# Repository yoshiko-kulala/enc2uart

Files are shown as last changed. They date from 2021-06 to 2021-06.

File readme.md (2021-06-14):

# enc2uart
とある理由でエンコーダを複数arduinoで読む必要出たので作った  
[nucleo-F401RE](https://akizukidenshi.com/catalog/g/gM-07723/)でエンコーダを4つ読んでuartで送っている  

## Hou to use  
### シールド基板、エンコーダとの配線
使用時にはこのようなシールド基板を用いて動作させている  
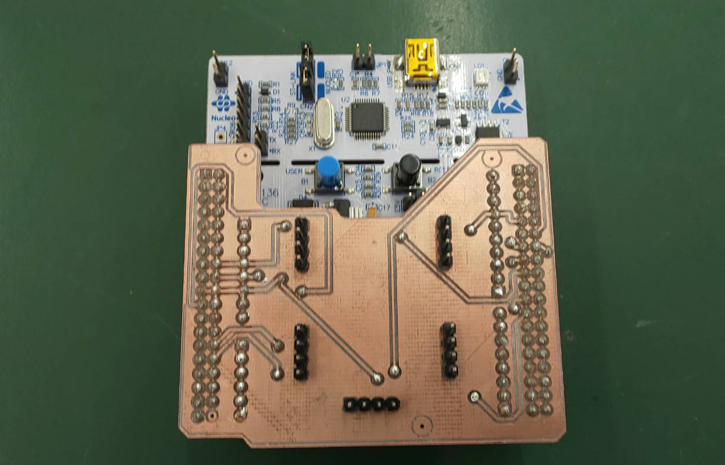
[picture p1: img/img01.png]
  
基板のkicadデータ、ガーバーは[circuit/encoder](https://github.com/yoshiko-kulala/enc2uart/tree/master/circuit/encoder)にある  
回路図は最新だが、ボード図はプルアップ抵抗のないものになっている  

実際にはこのように配線すればOK  
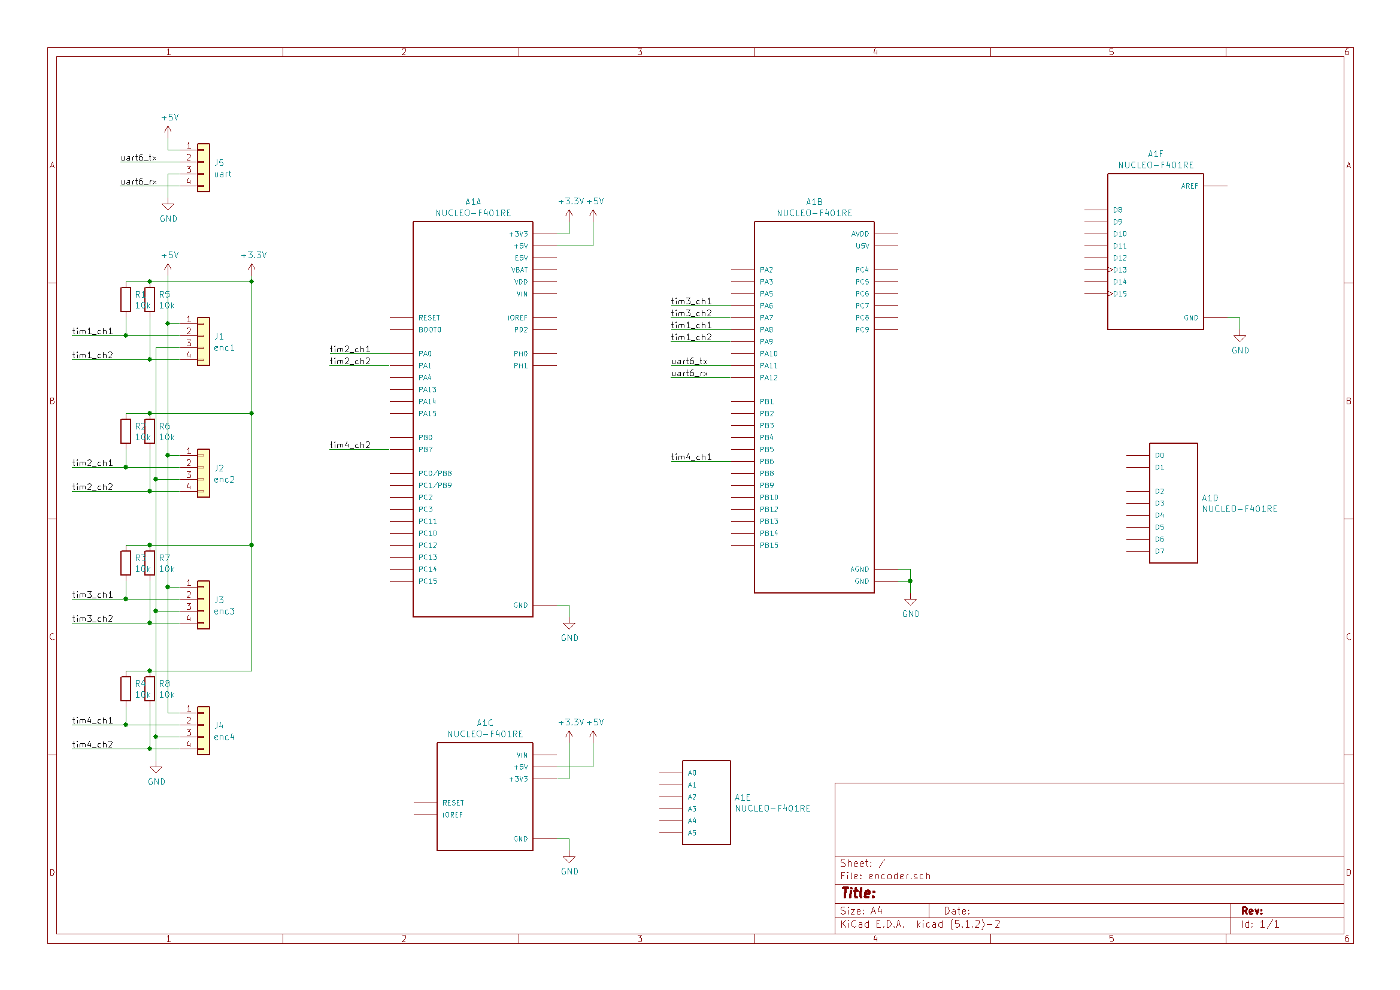
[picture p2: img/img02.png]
  

### arduinoとの接続  
[arduino nano every](https://akizukidenshi.com/catalog/g/gM-14848/)を用いたのでserial1を使っている  
arduinoによっては[SoftwareSerial](http://www.musashinodenpa.com/arduino/ref/index.php?f=1&pos=120)でも同様に動作可能と思う  
f401側のuartとarduino側のuartを接続すればOK  
今回は下図のように接続した
| [arduino nano every](https://akizukidenshi.com/catalog/g/gM-14848/) | [nucleo-F401RE](https://akizukidenshi.com/catalog/g/gM-07723/) |
| --- | --- |
| 5V | 5V(arduinoから給電する場合) |
| D0 | Tx |
| GND | GND |
| D1 | Rx |

## プログラムサンプル
nucleo側プログラムは[src/encoder_test](https://github.com/yoshiko-kulala/enc2uart/tree/master/src/encoder_test)にある  
CubeIDEでそのまま書き込める(と思う)  

arduino側のプログラムは[src/read_data](https://github.com/yoshiko-kulala/enc2uart/tree/master/src/read_data)にある  
これもarduinoIDEで特に問題なく書き込めると思う  

## メモ
- データの中身
実際に送ってる値は10msごとのパルスの増減  
特に計算してないのでエンコーダの分解能によってarduino側(もしくはnucleo)で処理されたし  
- 送信時の話し  
エンコーダ1つに10bit、4つで40bitなので5byteにして送信している  
つまるところ、100msに512パルス以上来るとオーバーする  
特にその辺の処理入れてないので将来的に追加するかも  
- nucleoからのデバッグ  
nucleoとpcをusb接続して、teratermとかで115200bpsとかで読んでもらうと各エンコーダの値が出力される  
これが0ならエンコーダとnucleo間が怪しい  
これが出てたらnucleoとarduino間が怪しい

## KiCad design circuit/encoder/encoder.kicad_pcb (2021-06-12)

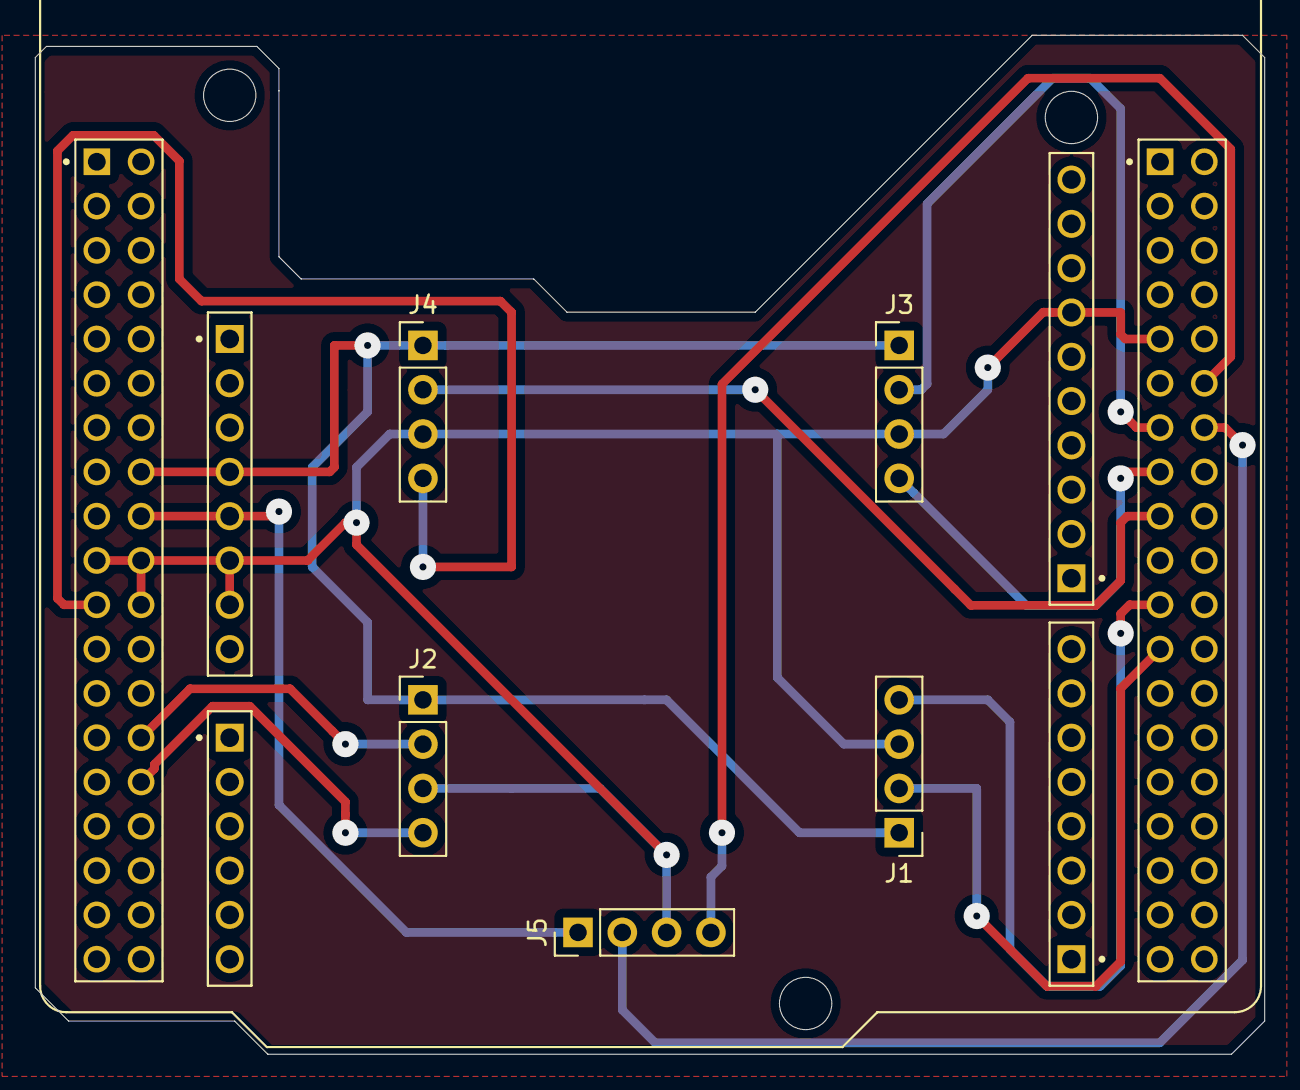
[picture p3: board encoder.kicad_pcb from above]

Board: 2 copper layers, 70.5 x 58.4 mm, 6 parts (0 on the bottom side), 13 nets.

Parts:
A1: NUCLEO-F401RE; ST_NUCLEO-F401RE
J1: enc1; PinHeader_1x04_P2.54mm_Vertical
J2: enc2; PinHeader_1x04_P2.54mm_Vertical
J3: enc3; PinHeader_1x04_P2.54mm_Vertical
J4: enc4; PinHeader_1x04_P2.54mm_Vertical
J5: uart; PinHeader_1x04_P2.54mm_Vertical

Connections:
+3V3: A1.CN6_4, A1.CN7_16, J1.1, J2.1, J3.1, J4.1
+5V: A1.CN6_5, A1.CN7_18, J5.1
/tim1_ch1: A1.CN10_23, J1.2
/tim1_ch2: A1.CN10_21, J1.4
/tim2_ch1: A1.CN7_28, J2.2
/tim2_ch2: A1.CN7_30, J2.4
/tim3_ch1: A1.CN10_13, J3.2
/tim3_ch2: A1.CN10_15, J3.4
/tim4_ch1: A1.CN10_17, J4.2
/tim4_ch2: A1.CN7_21, J4.4
/uart6_rx: A1.CN10_12, J5.4
/uart6_tx: A1.CN10_14, J5.2
GND: A1.CN5_7, A1.CN6_6, A1.CN6_7, A1.CN7_8, A1.CN7_19, A1.CN7_20, A1.CN7_22, A1.CN10_9, A1.CN10_20, A1.CN10_32, J1.3, J2.3, J3.3, J4.3, J5.3

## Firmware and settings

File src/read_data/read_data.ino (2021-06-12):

uint8_t buf[4];
int rpm[4];
int prerpm[4];

void setup() {
  Serial.begin(115200);
  while (!Serial) {
  }

  Serial1.begin(115200);
}

void loop() { // run over and over
  if (Serial1.available() >4) {
    for (int i = 0; i < 5; i++) {
      buf[i] = Serial1.read();
    }
    //    Serial.print(buf[0]);
    //    Serial.print(",");
    //    Serial.print(buf[1]);
    //    Serial.print(",");
    //    Serial.print(buf[2]);
    //    Serial.print(",");
    //    Serial.print(buf[3]);
    //    Serial.print(",");
    //    Serial.println(buf[4]);
    for(int i=0;i<4;i++)prerpm[i]=rpm[i];    
    rpm[0] = buf[0] + ((buf[1] & 0x3) << 8);
    rpm[1] = ((buf[1] & 0xFC)>>2) + ((buf[2] & 0xF) << 6);
    rpm[2] = ((buf[2] & 0xF0)>>4) + ((buf[3] & 0x3F) << 4);
    rpm[3] = ((buf[3] & 0xC0)>>8) + (buf[4] << 2);
    for(int i=0;i<4;i++){
      rpm[i]=rpm[i]-500;
      if(abs(prerpm[i]-rpm[i])>40)rpm[i]=prerpm[i];
    }
    Serial.print(rpm[0]);
    Serial.print(",");
    Serial.print(rpm[1]);
    Serial.print(",");
    Serial.print(rpm[2]);
    Serial.print(",");
    Serial.println(rpm[3]);
  }
}

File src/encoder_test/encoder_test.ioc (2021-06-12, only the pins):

Mcu.UserName=STM32F401RETx
PA0-WKUP.Signal=S_TIM2_CH1_ETR
PA1.Signal=S_TIM2_CH2
PA11.Signal=USART6_TX
PA12.Signal=USART6_RX
PA13.GPIO_Label=TMS
PA13.Signal=SYS_JTMS-SWDIO
PA14.GPIO_Label=TCK
PA14.Signal=SYS_JTCK-SWCLK
PA2.GPIO_Label=USART_TX
PA2.Signal=USART2_TX
PA3.GPIO_Label=USART_RX
PA3.Signal=USART2_RX
PA5.GPIO_Label=LD2 [Green Led]
PA5.Signal=GPIO_Output
PA6.Signal=S_TIM3_CH1
PA7.Signal=S_TIM3_CH2
PA8.Signal=S_TIM1_CH1
PA9.Signal=S_TIM1_CH2
PB3.GPIO_Label=SWO
PB3.Signal=SYS_JTDO-SWO
PB6.Signal=S_TIM4_CH1
PB7.Signal=S_TIM4_CH2
PC13-ANTI_TAMP.GPIO_Label=B1 [Blue PushButton]
PC13-ANTI_TAMP.Signal=GPXTI13
PC14-OSC32_IN.Signal=RCC_OSC32_IN
PC15-OSC32_OUT.Signal=RCC_OSC32_OUT

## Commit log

2021-06-12 一旦完成
2021-06-14 細かなミスの修正
